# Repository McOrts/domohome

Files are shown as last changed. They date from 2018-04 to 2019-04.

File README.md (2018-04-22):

# Un Mosquitto controla mi casa
Este es un proyecto del tipo de los que nunca se acaban, Pero he querido ordenar y documentar la parte principal de este sistema de domótica que he instalado en mi casa, para poder compartirlo con la comunidad. 

Construido bajo los principios del _Do It Yourselft_, [aquí encontraréis todo el código](https://github.com/McOrts/domohome) Python, NodeJS, SQL y Node-RED utilizado. Así como las referencias al open-hardware utilizado: [Raspberry Pi](https://www.raspberrypi.org).

## Mi implementación del IOT

Para montar un sistema de domótica en casa se pueden aplicar muchas soluciones. Y en como tantas otras cosas. Hay una fácil y cara. Y otra difícil y barata. La mía es más bien de estas últimas.

La instalación descrita aquí funcionalmente se ocupa de:
- informarme y alertarme por twitter de:
	- cuándo amanece y anochece cada día. 
	- cual es la temperatura y humedad del trastero.
- Activar un deshumidificador en función de la hora del alba y del ocaso.
- Almacenar toda la información en una base de datos relacional y en Cloud.

El componente principal de la arquitectura que he utilizado el un _Broker_ de mensajería basado en _topic_. Los sensores están conectados a puertos GPIO de una mini-CPU que ejecuta un programa especifico para cada uno. Este programa realiza las siguientes tareas:
- Lee el valor del sensor. 
- Graba el valor en una BBDD relacional.
- Envía el valor a:
	- Una plataforma de _Cloud_ via API Rest.
	- Un mensaje MQTT a un _topic_ especifico.

Por encima de esta gestión corre una aplicación _middleware_ que subscrita a los _topics_, toma decisiones acerca de:
- Activar un dispositivo a través de puertos GPIO.
- Enviar avisos a Twitter.
- Ofrece un interface de usuario web para operar el sistema.
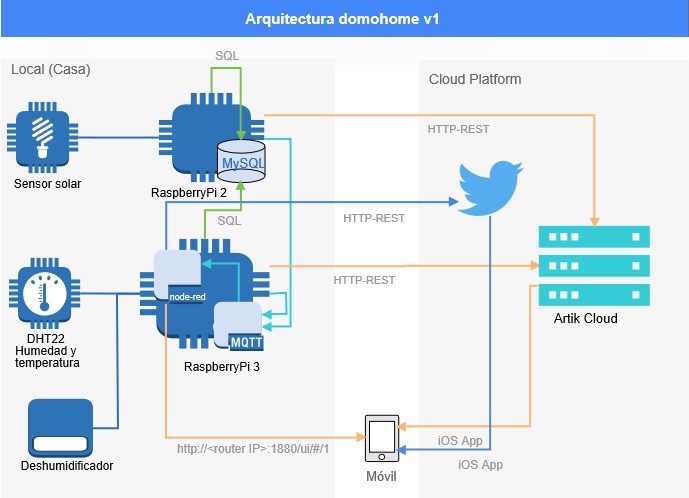
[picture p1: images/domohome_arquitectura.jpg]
Arquitectura domohome


Los sensores también se pueden construir incorporados en microcontroladores dedicados operando de forma autónoma. El valor entonces en enviado en un mensaje MQTT por un canal inalámbrico o físico a _broker_. En sucesivos artículos describiré otras muchas maneras de implementar sensores. 

## MQTT ¿Qué, cuándo y dónde?

En 1999 dos ingenieros, el Dr. Andy Stanford-Clark de IBM y Arlen Nipper de Eurotech. Estaban participando en la construcción de un oleoducto con el reto de conectar online sus 4.000 sensores a un sistema centralizado de SCADA. Utilizando un enlace de satélite como única comunicación posible.

Y así se diseñó este protocolo MQTT a fin de cumplir la restricción de utilizar una comunicación costosa, de banda estrecha y con latencias importantes. Siendo sus características principales:
- __Simple y ligero__. Con menos requerimientos de proceso y ancho de banda.
- __Tolerancia a altas latencias__. Lo que permite utilizar canales de comunicacion poco óptimos para otros protocolos.
- __Fiabilidad__ de entrega de mensajes. Incorpora tres niveles de calidad del servicio (QoS):
	- QoS 0: como máximo una vez. Esto implica que puede que no se entregue.
	- QoS 1: al menos una vez. Se garantiza la entrega pero puede que duplicados.
	- QoS 2: exactamente una vez. Se garantiza que llegará una vez el mensaje.

En 2012 Andy Stanford-Clark contó su experiencia y su visión del futuro de la IOT basado en MQTT en esta famosa conferencia TED:
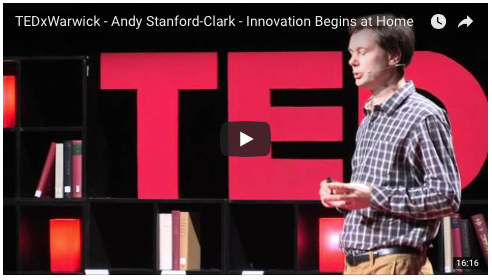
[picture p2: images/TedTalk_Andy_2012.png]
TEDxWarwick (https://youtu.be/s9nrm8q5eGg)


En 2011 IBM cedió el código a la fundación Eclipse liberándolo a la comunidad. De manera que su popularización le llevó a que en En 2014 se convirtiera en un estándar certificado por la Organización para la Adopción del Estándar de Comercio Electrónico y Servicios Web ( [OASIS](https://www.oasis-open.org/news/announcements/mqtt-version-3-1-1-becomes-an-oasis-standard)).
 
## Manos a la obra 

Lo primero, definir la estructura de los _topic_ que necesito usar. Un _topic_ al fin y al cavo, es un buzón público de correo que cualquiera puede leer. Con la caracteristica especial de que pueden organizarse gerárquimanente. En mi caso este es el árbol:
```
`-- home
    |-- meteo
    |   `-- solar
    `-- storageroom
        |-- humidity
        `-- temperature
```
Esta estructura y la sintaxis que se utiliza la podéis ver en el contenido del fichero [config.json](https://github.com/McOrts/domohome/blob/master/config.json?raw=true)
```
"domohome_humidity":{
    	"device_id": "xxxxxx",
    	"device_token": "xxxxxx",
	"gpio_pin_input": "4",
	"gpio_pin_output": "6",
	"max_warning": 70,
	"topic_humidity":"/home/storageroom/humidity",
	"topic_temperature":"/home/storageroom/temperature"
	},
```
### Hardware 
El proyecto está basado en el más clásico de las mini-CPUs. La Raspberry Pi. En mi caso he utilizado dos. Un modelo 2 para alojar el MySQL y el sensor solar y otro modelo 3 para alojar Mosquitto y el sensor de humedad y temperatura.
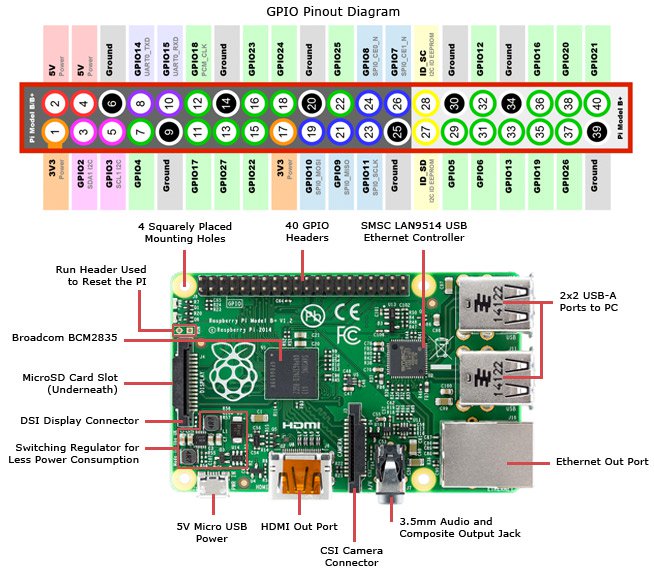
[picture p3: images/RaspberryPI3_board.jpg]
RaspberryPi3


La lista de materiales fundamentales es:
- [x] [Raspberry Pi 3](http://amzn.eu/7BqTe0q) Raspberry Pi 3 ó 2. 
- [x] [DHT22](http://amzn.eu/4mbH6zL) Módulo Sensor Digital Humedad y Temperatura
- [x] [Foto relé](https://www.aliexpress.com/item/Photodiode-module-detection-relay-module-combo-light-switch-light-photo-sensors/32336123938.html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,searchweb201602_1_10152_10065_10151_10344_10068_10342_10547_10343_10340_5722611_10341_10548_10698_10697_10696_5722911_5722811_10084_5722711_10083_10618_10307_10301_10303_5711211_10059_10184_308_100031_10103_441_10624_10623_10622_10621_10620_5711311_5722511,searchweb201603_32,ppcSwitch_7&algo_expid=57cc01a8-193e-436b-a32c-27b788d6b4c9-2&algo_pvid=57cc01a8-193e-436b-a32c-27b788d6b4c9&priceBeautifyAB=0) Cédula fotoeléctrica con relé.
- [x] [1PCS 2-channel ](https://www.aliexpress.com/item/2-channel-New-2-channel-relay-module-relay-expansion-board-5V-low-level-triggered-2-way/32713335353.html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,searchweb201602_1_10152_10065_10151_10344_10068_10342_10547_10343_10340_5722611_10341_10548_10698_10697_10696_5722911_5722811_10084_5722711_10083_10618_10307_10301_10303_5711211_10059_10184_308_100031_10103_441_10624_10623_10622_10621_10620_5711311_5722511-10620,searchweb201603_32,ppcSwitch_7&algo_expid=64447ff7-30cf-426d-a35e-27cfc1e18d9c-2&algo_pvid=64447ff7-30cf-426d-a35e-27cfc1e18d9c&priceBeautifyAB=0) Doble relé con alimentación de 5V.x

El circuito es muy simple. Necesitaremos 2 entradas y 2 salidas digitales. Además utilizaremos el pin de 5V y el GND (toma de tierra) para alimentar los sensores y relés:
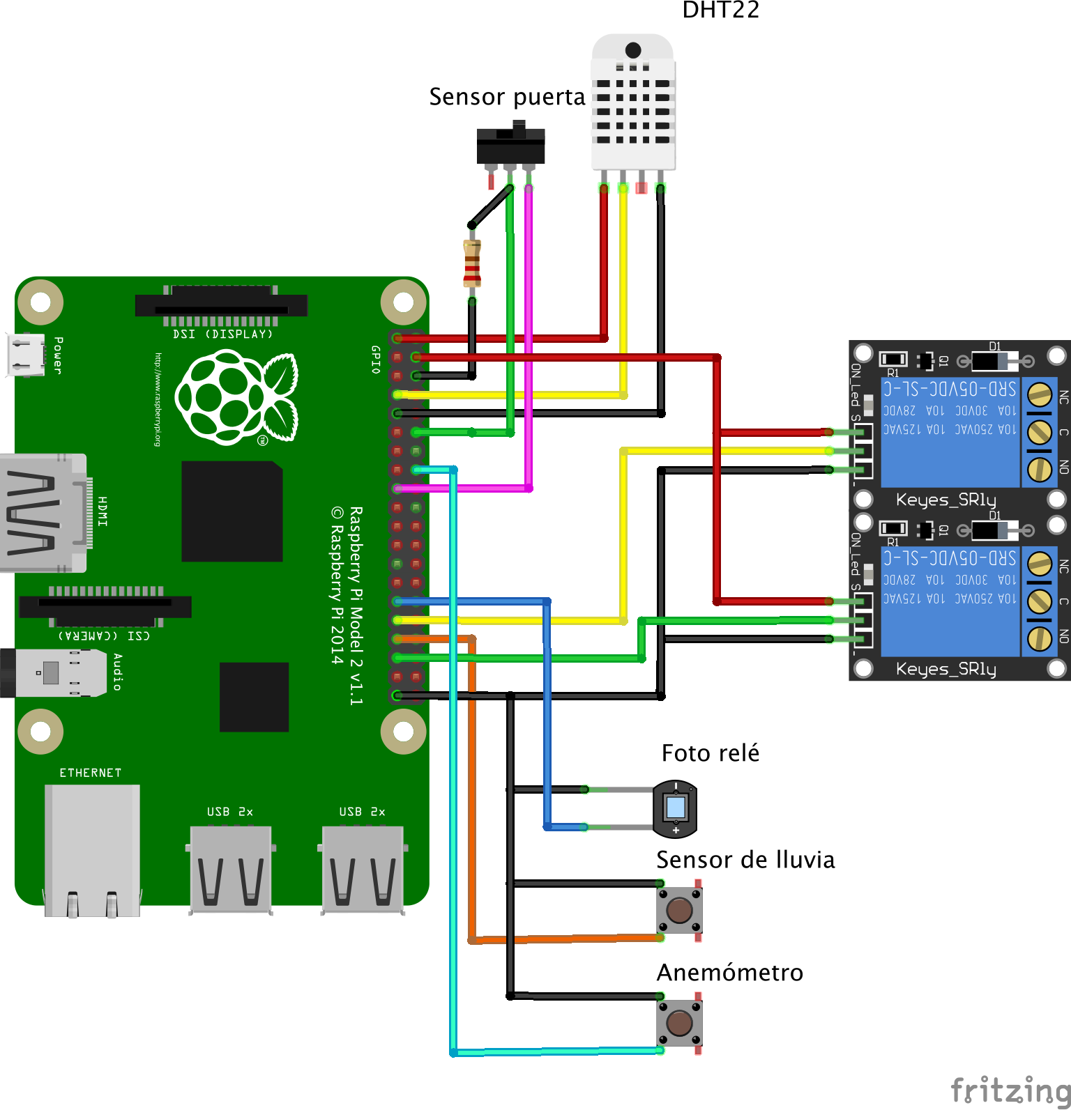
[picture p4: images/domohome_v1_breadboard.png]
Arquitectura breadboard


He montado todos los componentes en una amplia caja de plástico con sitio para poder incorporar más dispositivos:

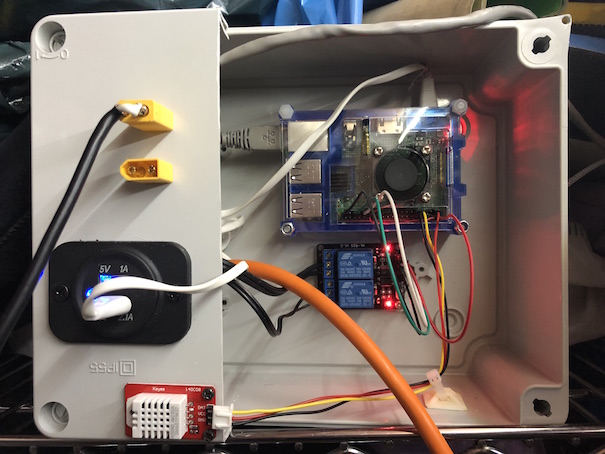
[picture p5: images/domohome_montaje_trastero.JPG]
domohome_montaje_trastero


### Servicios de cloud en Samsung Artik
Proviene de la antigua plataforma que se llamaba SAMlio y posteriormente SmartThings. El concepto original era dar soporte a dispositivos médicos y de salud. Pero rápidamente se dieron cuenta que también podrían dar soporte a proyectos del IoT. De aquí surgió Artik Cloud, donde han unificado tanto hardware y software.

Mi caso de uso es solo para almacenar informacion y mostrarla a través de la apliación móvil:
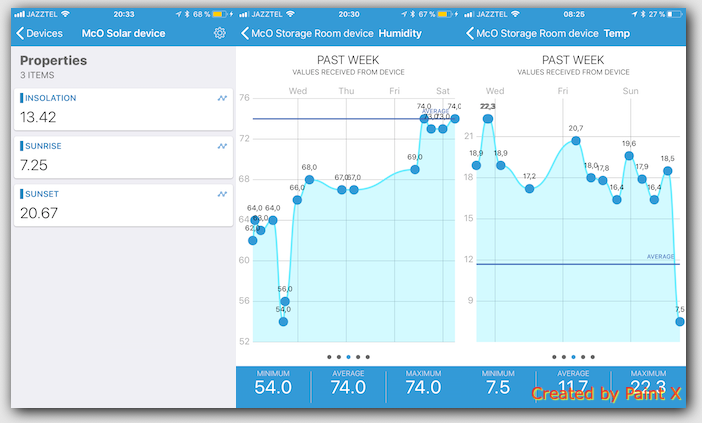
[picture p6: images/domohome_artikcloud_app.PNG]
domohome_artikcloud_app


Es compatible con Amazón Echo (interfaz de voz), Fitbit (monitor de actividad), Nest (termostato de Google) y, por supuesto, con Samsung. Si quieres saber todas las plataformas que son compatibles puedes acceder a su web oficial. Una de las mayores ventajas es que soporta IFTTT, lo que nos permite comunicación con cualquier cosa que te puedas imaginar.

Por otra parte tiene un plan de precios con un tramo gratuito. Está limitado a un uso que encaja perfectamente en un proyecto de este tipo.
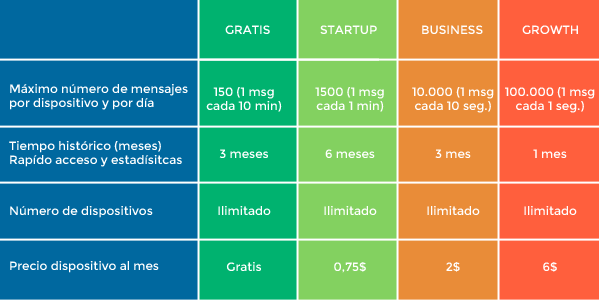
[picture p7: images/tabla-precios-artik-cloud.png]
artikcloud_precios


### Software
El **broker** elegido para Raspberry Pi es [Eclipse Mosquitto](https://mosquitto.org). Las instrucciones para su instalación las tenéis en múltiples webs. 
mosquitto-text-side

Por otra parte necesitamos muchas **librerías de Python** pàra que todo esto se pueda utilizar. Aconsejo paciencia para instalar y muchas veces reinstalar las más adecuadas. Para la mensajería MQTT he utilizado [Eclipse Paho MQTT Python client library](https://pypi.python.org/pypi/paho-mqtt) es simple y que funciona muy bien.

En la parte del **middleware** tenemos [Node-RED](https://nodered.org). Nos permite programar todos nuestros interfaces, colas, webservices, sockets, APIs... de forma gráfica. Y además generar un interface de usuario web responsivo perfecto para dispositivos móviles. Una maravilla desarrollada por _IBM’s Emerging Technology Services team_ y ahora es parte de JS Foundation. La **base de datos** relacional es MySQL. Un clásico fácil de instalar. 

He desarrollado un sencillo _dashboard_ para conocer los valores ambientales de mi trastero, poder activar dispositivos y luces y conocer los eventos y valores meteorológicos:
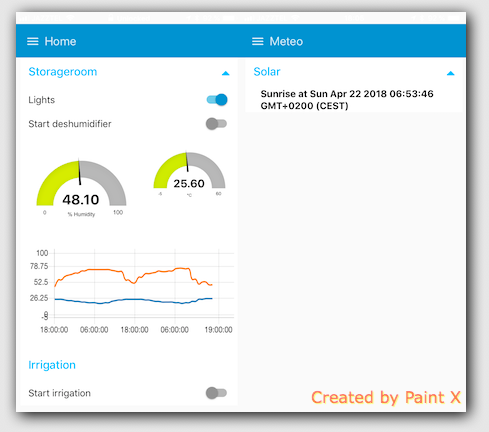
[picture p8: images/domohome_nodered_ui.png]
domohome_nodered_ui


Y ¿Cómo se maneja todo esto? Simplemente dibujando flujos entre ´nodos´ muy fácilmente configurables. Así, por ejemplo, tenemos un nodo para suscribirnos a topics MQTT u otro para activar puertos QPIO de las Raspberry PI. Incluso hay para interactuar con un Alexa Echo.

Este es el flujo para el control de humedad:
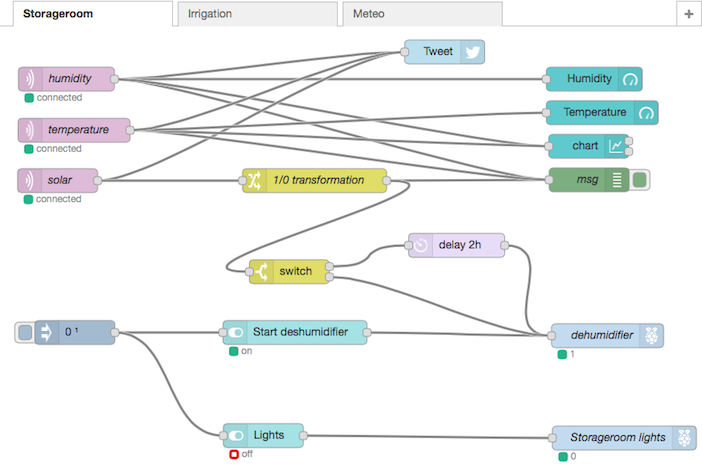
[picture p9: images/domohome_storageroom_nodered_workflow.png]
domohome_storageroom_nodered_workflow


Como se puede ver tiene un node para Tweeter. Y así quedan los tweet en el dashboard de la cuenta del dispositivo:
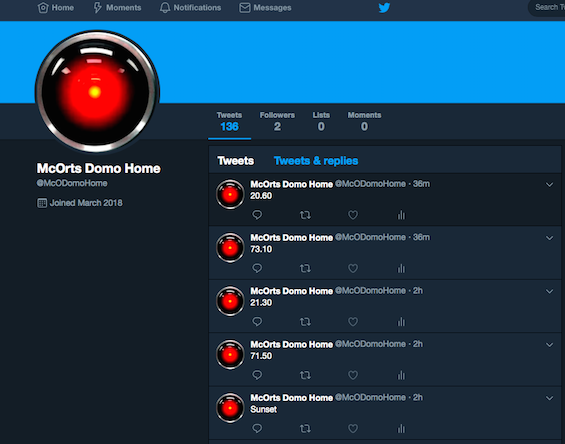
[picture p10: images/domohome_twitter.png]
domohome_twitter


## Agradecimientos y referencias
- [MQTT.org](http://mqtt.org)
- Una vez más a Luis del Valle de [ProgramarFacil](https://programarfacil.com) por su artículo ["Cómo conectar MQTT con ESP8266, Raspberry Pi y Mosquitto"](https://programarfacil.com/esp8266/mqtt-esp8266-raspberry-pi/)
- R. A. Light, "Mosquitto: server and client implementation of the MQTT protocol," The Journal of Open Source Software, vol. 2, no. 13, May 2017, DOI: [10.21105/joss.00265](http://dx.doi.org/10.21105/joss.00265)
- IBM Developers [MQTT: Enabling the Internet of Things](https://developer.ibm.com/messaging/2013/04/26/mqtt-enabling-internet-things/)

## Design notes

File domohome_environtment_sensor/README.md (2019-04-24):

https://lastminuteengineers.com/pir-sensor-arduino-tutorial/

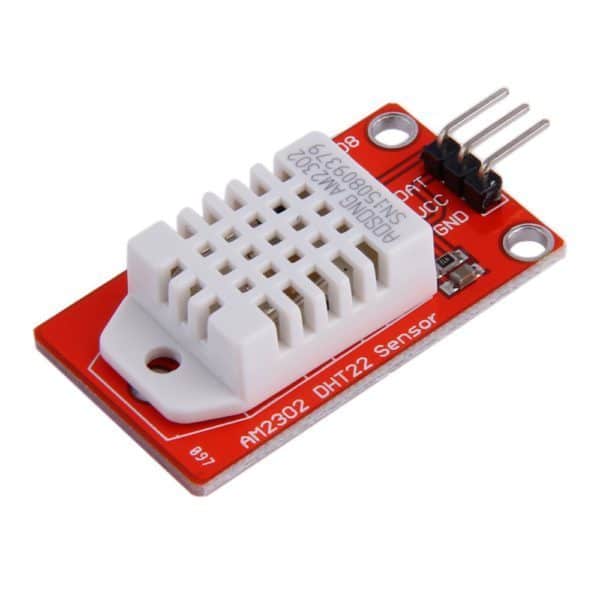
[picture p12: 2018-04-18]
images/DHT22-Humdity_Temperature.jpg

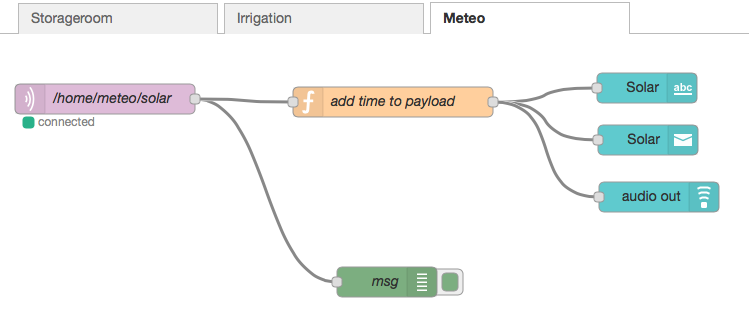
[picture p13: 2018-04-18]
images/domohome_solar_nodered_workflow.png

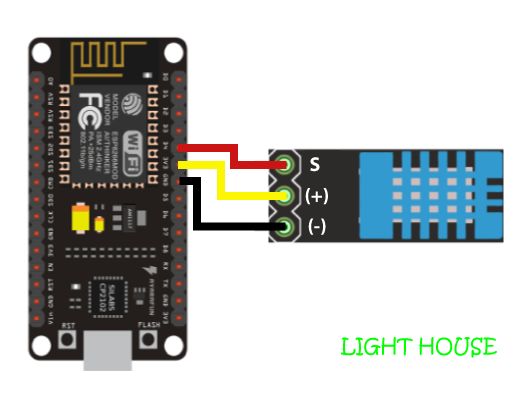
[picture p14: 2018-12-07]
images/nodeMCU_sensor_breadboard.jpg

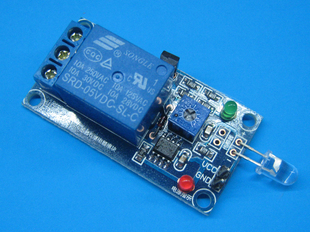
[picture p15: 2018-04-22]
images/Photodiode-module-detection-relay.jpg

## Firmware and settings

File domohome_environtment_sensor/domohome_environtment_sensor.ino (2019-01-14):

#include <ESP8266WiFi.h>
#include <PubSubClient.h>
#include <Wire.h>
#include <Adafruit_Sensor.h>
#include <DHT.h>
#include <DHT_U.h>
#include <Adafruit_NeoPixel.h>
#ifdef __AVR__
  #include <avr/power.h>
#endif

#include "settings.h"

// Configuración cliente WiFi
WiFiClient espClient;

// Configuración MQTT
PubSubClient clientMqtt(espClient);
long lastMsg = 0;
char msg[50];
String mqttcommand = String(14);

/* Configuración sensor NEOPIXEL */
#define PIN_STRIP_1 2
#define NUMPIXELS_STRIP_1 7
Adafruit_NeoPixel pixels_STRIP_1  = Adafruit_NeoPixel(NUMPIXELS_STRIP_1, PIN_STRIP_1, NEO_GRB + NEO_KHZ800);


/* Configuración sensor DHT22 */
#define DHTPIN            4  
#define DHTTYPE           DHT22     // DHT 22 (AM2302)
float temperature;
float humidity;
DHT_Unified dht(DHTPIN, DHTTYPE);
uint32_t delayMS;

void setup() {
  Serial.begin(115200);

  /* Iiniciar NEOPIXEL */
  pixels_STRIP_1.begin(); // This initializes the NeoPixel library. 
  for(int i=0;i<NUMPIXELS_STRIP_1;i++){
     pixels_STRIP_1.setPixelColor(i, pixels_STRIP_1.Color(0,0,0)); // black color.
     pixels_STRIP_1.show(); // This sends the updated pixel color to the hardware.
  }

  /* Iiniciar wifi */
  setup_wifi();
  clientMqtt.setServer(mqtt_server, mqtt_port);
  clientMqtt.setCallback(callback);

  /* Iiniciar sensor */
  dht.begin();
  Serial.println("DHT22 Unified Sensor initialization");
    // Print temperature sensor details.
  sensor_t sensor;
  dht.temperature().getSensor(&sensor);
  Serial.println("------------------------------------");
  Serial.println("Temperature");
  Serial.print  ("Sensor:       "); Serial.println(sensor.name);
  Serial.print  ("Driver Ver:   "); Serial.println(sensor.version);
  Serial.print  ("Unique ID:    "); Serial.println(sensor.sensor_id);
  Serial.print  ("Max Value:    "); Serial.print(sensor.max_value); Serial.println(" *C");
  Serial.print  ("Min Value:    "); Serial.print(sensor.min_value); Serial.println(" *C");
  Serial.print  ("Resolution:   "); Serial.print(sensor.resolution); Serial.println(" *C");  
  Serial.println("------------------------------------");
  // Print humidity sensor details.
  dht.humidity().getSensor(&sensor);
  Serial.println("------------------------------------");
  Serial.println("Humidity");
  Serial.print  ("Sensor:       "); Serial.println(sensor.name);
  Serial.print  ("Driver Ver:   "); Serial.println(sensor.version);
  Serial.print  ("Unique ID:    "); Serial.println(sensor.sensor_id);
  Serial.print  ("Max Value:    "); Serial.print(sensor.max_value); Serial.println("%");
  Serial.print  ("Min Value:    "); Serial.print(sensor.min_value); Serial.println("%");
  Serial.print  ("Resolution:   "); Serial.print(sensor.resolution); Serial.println("%");  
  Serial.println("------------------------------------");
  // Set delay between sensor readings based on sensor details.
  delayMS = sensor.min_delay / 1000;
}

void setup_wifi() {
  delay(10);

  // Comienza el proceso de conexión a la red WiFi
  Serial.println();
  Serial.print("[WIFI]Conectando a ");
  Serial.println(ssid);

  // Modo estación
  WiFi.mode(WIFI_STA);
  // Inicio WiFi
  WiFi.begin(ssid, password);

  while (WiFi.status() != WL_CONNECTED) {
    delay(500);
    Serial.print(".");
  }

  Serial.println("");
  Serial.println("[WIFI]WiFi conectada");
  Serial.print("[WIFI]IP: ");
  Serial.print(WiFi.localIP());
  Serial.println("");
}

void callback(char* topic, byte* payload, unsigned int length) {
  Serial.print("[MQTT]Mensaje recibido (");
  Serial.print(topic);
  Serial.print(") ");
  mqttcommand = "";
  for (int i = 0; i < length; i++) {
    mqttcommand += (char)payload[i];
  }
  Serial.print(mqttcommand);
  Serial.println();
  // Switch on the LED if an 1 was received as first character
  if (mqttcommand == "LightOn") {
    pixels_STRIP_1.setPixelColor(0, pixels_STRIP_1.Color(255,255,55));
    pixels_STRIP_1.setPixelColor(1, pixels_STRIP_1.Color(255,255,55));
    pixels_STRIP_1.setPixelColor(5, pixels_STRIP_1.Color(255,255,55));
    pixels_STRIP_1.setPixelColor(6, pixels_STRIP_1.Color(255,255,55));
    pixels_STRIP_1.setPixelColor(2, pixels_STRIP_1.Color(255,255,255));
    pixels_STRIP_1.setPixelColor(3, pixels_STRIP_1.Color(255,255,255));
    pixels_STRIP_1.setPixelColor(4, pixels_STRIP_1.Color(255,255,255));
    pixels_STRIP_1.show(); // This sends the updated pixel color to the hardware.
    Serial.println("LightOn");
  } else if (mqttcommand == "LightOff"){
    for(int i=0;i<NUMPIXELS_STRIP_1;i++){
      pixels_STRIP_1.setPixelColor(i, pixels_STRIP_1.Color(0,0,0)); // black color.
      pixels_STRIP_1.show(); // This sends the updated pixel color to the hardware.
    }
    Serial.println("LightOff");
  } else if (mqttcommand == "Alarm"){
    for (int q=0; q < 100; q++) {
      for(int i=0;i<NUMPIXELS_STRIP_1;i++){
        pixels_STRIP_1.setPixelColor(i, pixels_STRIP_1.Color(255,255,255)); // high bright white color.
        pixels_STRIP_1.show(); // This sends the updated pixel color to the hardware.
      }
      for(int i=0;i<NUMPIXELS_STRIP_1;i++){
        pixels_STRIP_1.setPixelColor(i, pixels_STRIP_1.Color(0,0,0)); // black color.
        pixels_STRIP_1.show(); // This sends the updated pixel color to the hardware.
      }
      delay(100);
    }
    Serial.println("Alarm");
  }
}

void reconnect() {
  Serial.print("[MQTT]Intentando conectar a servidor MQTT... ");
  // Bucle hasta conseguir conexión
  while (!clientMqtt.connected()) {
    Serial.print(".");
    // Intento de conexión
    if (clientMqtt.connect(mqtt_id)) { // Ojo, para más de un dispositivo cambiar el nombre para evitar conflicto
      Serial.println("");
      Serial.println("[MQTT]Conectado al servidor MQTT");
      // Once connected subscribe
      clientMqtt.subscribe(mqtt_sub_topic_operation);
    } else {
      Serial.print("[MQTT]Error, rc=");
      Serial.print(clientMqtt.state());
      Serial.println("[MQTT]Intentando conexión en 5 segundos");

      delay(5000);
    }
  }
}

void loop() {
  if (!clientMqtt.connected()) {
    reconnect();
  }
  clientMqtt.loop();

  long now = millis();
  if (now - lastMsg > update_time) {
    lastMsg = now;

    /* Publicación de temperatura y presión en cada topic */
    sensors_event_t event;  
    dht.temperature().getEvent(&event);
    if (isnan(event.temperature)) {
      Serial.println("Error reading temperature!");
    }
    else {
      Serial.print("Temperature: ");
      temperature = event.temperature;
      Serial.print(temperature);
      Serial.println(" *C");
      snprintf (msg, 6, "%2.1f", temperature);
      Serial.print("[MQTT]Enviando mensaje de temperatura: ");
      Serial.println(msg);
      clientMqtt.publish(mqtt_pub_topic_temperature, msg);
    }
    // Get humidity event and print its value.
    dht.humidity().getEvent(&event);
    if (isnan(event.relative_humidity)) {
      Serial.println("Error reading humidity!");
    }
    else {
      Serial.print("Humidity: ");
      humidity = event.relative_humidity;
      Serial.print(humidity);
      Serial.println("%");
      snprintf (msg, 6, "%2.1f", humidity);
      Serial.print("[MQTT]Enviando mensaje de humedad: ");
      Serial.println(msg);
      clientMqtt.publish(mqtt_pub_topic_humidity, msg);
    }
  }
}

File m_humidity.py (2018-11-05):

#!/usr/bin/python
# -*- coding: utf-8 -*-

#import RPi.GPIO as GPIO
import artikcloud
from artikcloud.rest import ApiException
import smtplib
import datetime
import time
import MySQLdb as mdb
import logging
import os
import fnmatch
import math
import json
from pprint import pprint
import sys

#PYTHON 3
#import asyncio
#PYTHON 2
import trollius as asyncio

import websocket
import Adafruit_DHT as dht
import paho.mqtt.client as mqtt

# To avoid the error on rc.local execution envirotment: 
#WARNING urllib3.connectionpool Retrying (Retry(total=2, connect=None, read=None, redirect=None, status=None)) after connection broken by 'NewConnectionError('<urllib3.connection
logging.getLogger("urllib3").setLevel(logging.ERROR)

# Then the code sets up the logging module. We are going to use the basicConfig() function to set up the default handler 
# so that any debug messages are written to the file /home/pi/event_error.log.
logging.basicConfig(filename='/home/pi/humidity_event_error.log',
  level=logging.DEBUG,
  format='%(asctime)s %(levelname)s %(name)s %(message)s')
logger=logging.getLogger(__name__)

# Read the configuration file
DEFAULT_CONFIG_PATH = '/home/pi/config.json'
with open(DEFAULT_CONFIG_PATH, 'r') as config_file:
  config = json.load(config_file)

# Function for storing readings into MySQL
def insertDB(humidity,temperature):
  try:
    con = mdb.connect(config['db_server_ip'],
                      config['db_update_user'],
                      config['db_update_password'],
                      'measurements');
    cursor = con.cursor()
    sql = "INSERT INTO humidity(humidity_percentage,temperature) VALUES ('%s', '%s')" % (humidity,temperature)
    cursor.execute(sql)
    sql = []
    con.commit()
    con.close()
  except mdb.Error as e:
    logger.error(e)

# Function for send an email notifing the humidity reach the maximum 
def send_email_humidity(p_cc, p_humidity, p_temperature):
    # Specifying the from and to addresses
    fromaddr = config['mail']['fromaddr']
    toaddr = config['mail']['toaddr']
    cc = config['mail']['cc']
#    bcc = ['mail@dominio.com']
    message_subject = "[HUMIDITY] Home humidity alert"
    message_text = "The humidity is: %s" % '{:3.2f}'.format(p_humidity / 1.) + " with a temperature of: %s" % '{:3.2f}'.format(p_temperature / 1.)+ "C"
    if p_cc:
      # cc version
      message = "From: %s\r\n" % fromaddr + "To: %s\r\n" % toaddr + "CC: %s\r\n" % ",".join(cc) + "Subject: %s\r\n" % message_subject + "\r\n"  + message_text
      toaddrs = [toaddr] + [cc] 
    else:
      message = "From: %s\r\n" % fromaddr + "To: %s\r\n" % toaddr + "Subject: %s\r\n" % message_subject + "\r\n"  + message_text
      toaddrs = [toaddr]
    # Sending the mail  
    try:
      server = smtplib.SMTP_SSL("smtp.gmail.com", 465)
      server.ehlo()
      server.login(config['mail']['username'],config['mail']['password'])
      # ssl server doesn't support or need tls, so don't call server.starttls() 
      server.sendmail(fromaddr, toaddrs, message)
      server.close()
      # print 'successfully sent the mail'
    except:
      print ("failed to send mail")

# Function for send  the data to de IOT Cloud
def send_data_IOT_cloud(p_humidity, p_temperature):
  try:
    # SDK reference for more details
    # https://github.com/artikcloud/artikcloud-python

    # Configure Oauth2 access_token for the client application.  Here we have used
    # the device token for the configuration
    artikcloud.configuration = artikcloud.Configuration();
    artikcloud.configuration.access_token = config['domohome_storageroom_humidity']['device_token']

    # We create an instance of the Message API class which provides
    # the send_message() and get_last_normalized_messages() api call
    # for our example
    api_instance = artikcloud.MessagesApi()

    # Device_message - data that is sent to your device
    device_message = {}
    device_message['humidity']=int(round(p_humidity, 0))
    device_message['temp']=round(p_temperature, 1)

    # Set the 'device id' - value from your config.json file
    device_sdid = config['domohome_storageroom_humidity']['device_id']

    # set your custom timestamp
    ts = None

    # Construct a Message object for your request
    data = artikcloud.Message(device_message, device_sdid, ts)
    #print(data)

    #pprint(artikcloud.configuration.auth_settings())

    # Send Message
    api_response = api_instance.send_message(data)
    #pprint(api_response)

  except Exception as e:
    pprint("Exception when calling MessagesApi->send_message: %s\n" % e)
    logger.error("Exception when calling MessagesApi->send_message: %s\n" % e)

# Function for publish MQTT messages
def publish_MQTT_messages (p_humidity, p_temperature):
  try:
    client = mqtt.Client()
    # compose the message of humidity
    topic = config['domohome_storageroom_humidity']['topic_humidity']
    payload = '{:3.2f}'.format(p_humidity / 1.)
#    print ("Publishing " + payload + " to topic: " + topic + " ...")
    client.connect(config['MQTT']['broker_server_ip'],1883,60)
    client.publish (topic, payload)

    # compose the message of temperature
    topic = config['domohome_storageroom_humidity']['topic_temperature']
    payload = '{:3.2f}'.format(p_temperature / 1.)
#    print "Publishing " + payload + " to topic: " + topic + " ..."
    client.connect(config['MQTT']['broker_server_ip'],1883,60)
    client.publish (topic, payload)

    client.disconnect();
  except Exception as e:
    print ("exception")
    logger.error("Exception MQTT sending message: %s\n"+" "+e.__str__())

while True:
  # Read agein the configuration file for hot changes
  DEFAULT_CONFIG_PATH = '/home/pi/config.json'
  with open(DEFAULT_CONFIG_PATH, 'r') as config_file:
    config = json.load(config_file)

  # Read the measurements
  humidity,temperature = dht.read_retry(dht.DHT22, config['domohome_storageroom_humidity']['gpio_pin'])
#  print('{:3.2f}'.format(humidity / 1.))
#  print('{:3.2f}'.format(temperature / 1.))

  # Store the measurements in the DDBB
  insertDB (humidity,temperature)

  # Send an warning email if the humidity reach at maximum
  if humidity > config['domohome_storageroom_humidity']['max_warning']:
    send_email_humidity(True,humidity,temperature)

  # send the data to de IOT Cloud
  send_data_IOT_cloud (humidity,temperature)

  # publish MQTT messages
  publish_MQTT_messages (humidity,temperature)

  time.sleep(3600)

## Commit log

2018-04-18 cambio de nombres
2018-04-21 Scripts de las tablas MySQL
2018-05-01 Actualización para añadir un sensor de puerta y saber quién está en casa buscando la MacAdress de su móvil.
    [domohome_v1_breadboard.fzz]
2018-05-06 Actualizacion para sensor de lluvia y viento. Ajustes en el sensor de puerta.
    [domohome_v1_breadboard.fzz]
2019-01-14 peripheral sensor based on WeMos
